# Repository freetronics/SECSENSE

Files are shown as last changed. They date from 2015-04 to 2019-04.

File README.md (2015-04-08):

Security Sensor Shield for Arduino
==================================
Copyright 2013 Freetronics Pty Ltd  
Freetronics site:  www.freetronics.com  
Freetronics email: info@freetronics.com  

Based on the circuit described in the "Security / Automation Sensors"
project in the book "Practical Arduino", this shield allows up to 4
security sensors to be connected with full End-Of-Line (EOL) support to
detect tampering.

Supported sensors include:

 * PIR (passive infrared) motion detectors.
 * Microwave motion detectors.
 * Reed switches.
 * Glass break detectors.
 * Gas detectors.

End-Of-Line technology allows the system to detect a variety of events
using a single cable pair to the sensor, including:

 * Sensor triggered.
 * Sensor cable cut.
 * Sensor cable short-circuited.
 * Sensor housing opened (even when system is disarmed)

Compatible with the Freetronics Eleven, Arduino Uno, and other
compatible boards based on the same header format.

Features:

 * Supports 4 sensor channels simultaneously.
 * Sensor power supply connections totally isolated from the Arduino.
 * Status LED for each sensor channel.
 * Reset button wired through to Arduino reset pin.
 * Green "Sensor power on" LED.
 * Blue "Arduino power on" LED.
 * Overlay guide where you need it: both top and bottom.

More information is available at:

  http://www.freetronics.com/secsense  
  http://www.practicalarduino.com/projects/security-sensors

INSTALLATION
------------
The design is saved as an EAGLE project. EAGLE PCB design software is
available from www.cadsoftusa.com free for non-commercial use. To use
this project download it and place the directory containing these files
into the "eagle" directory on your computer. Then open EAGLE and
navigate to Projects -> eagle -> SECSENSE.

DISTRIBUTION
------------
The specific terms of distribution of this project are governed by the
license referenced below.

LICENSE
-------
Licensed under the TAPR Open Hardware License (www.tapr.org/OHL).
The "license" folder within this repository also contains a copy of
this license in plain text format.

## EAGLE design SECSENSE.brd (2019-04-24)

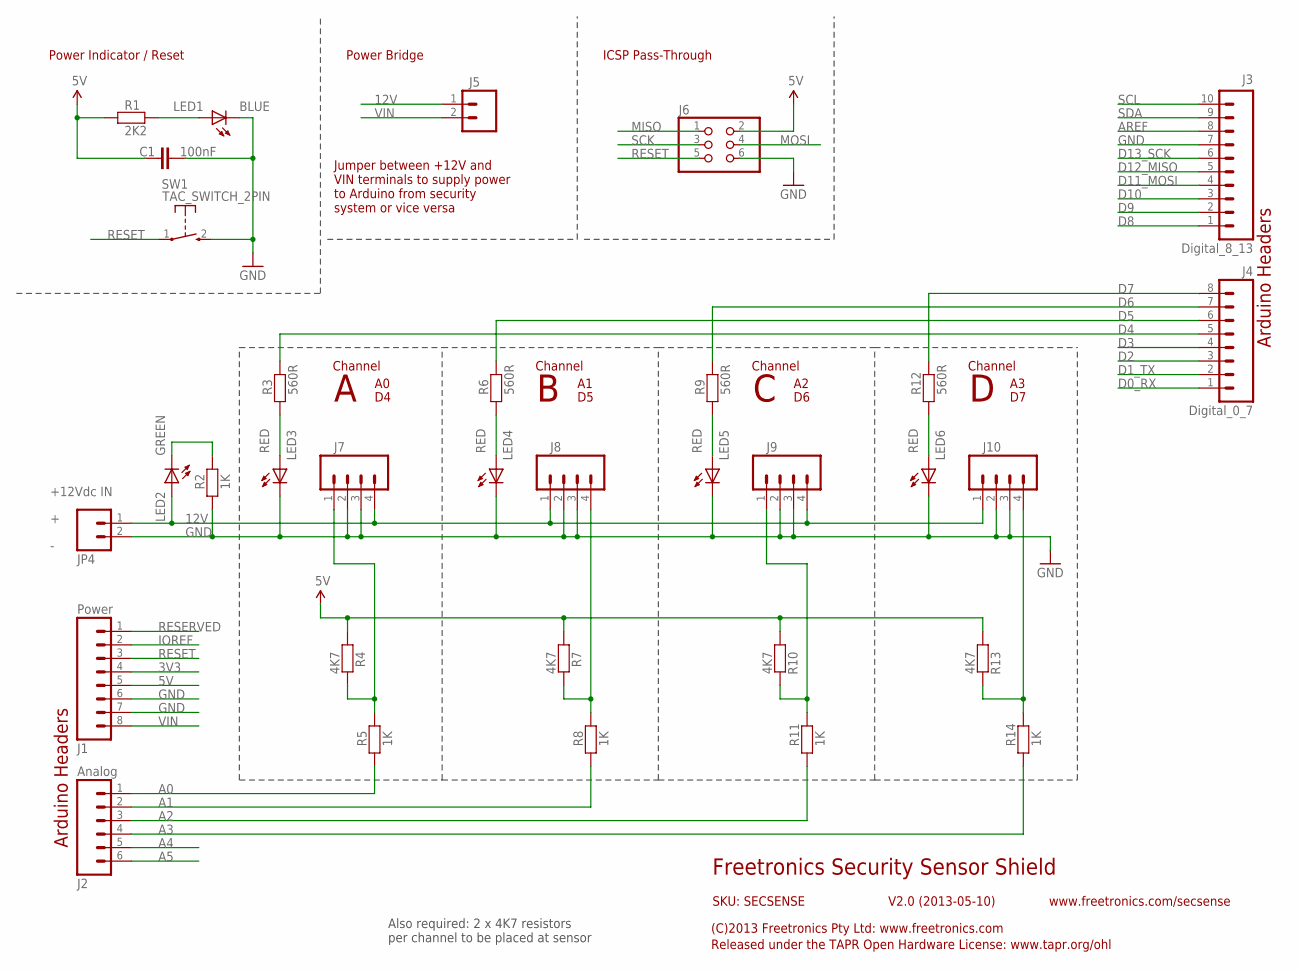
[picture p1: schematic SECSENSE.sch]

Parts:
C1: 100nF; 0603
J1: Power; 1X08
J2: Analog; 1X06
J3: Digital_8_13; 1X10
J4: Digital_0_7; 1X08
J5: M02PTH; 1X02
J6: PINHD-2X3; 2X03
J7, J8, J9, J10: M04SCREW; SCREWTERMINAL-3.5MM-4
JP4: M023.5MM; SCREWTERMINAL-3.5MM-2
LED1: BLUE; LED-0603
LED2: GREEN; LED-0603
LED3, LED4, LED5, LED6: RED; LED-0603
R1: 2K2; 0603
R2, R5, R8, R11, R14: 1K; 0603
R3, R6, R9, R12: 560R; 0603
R4, R7, R10, R13: 4K7; 0603
SW1: TAC_SWITCH_2PIN; TACTILE_SWITCH_SMD_2PIN_TINY

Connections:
3V3: J1.4
5V: C1.1, J1.5, J6.2, R1.1, R4.1, R7.1, R10.1, R13.1
12V: J5.1, J7.4, J8.1, J9.4, J10.1, JP4.1, LED2.A
A0: J2.1, R5.1
A1: J2.2, R8.1
A2: J2.3, R11.1
A3: J2.4, R14.1
A4: J2.5
A5: J2.6
AREF: J3.8
D0_RX: J4.1
D1_TX: J4.2
D2: J4.3
D3: J4.4
D4: J4.5, R3.2
D5: J4.6, R6.2
D6: J4.7, R9.2
D7: J4.8, R12.2
D8: J3.1
D9: J3.2
D10: J3.3
D11_MOSI: J3.4
D12_MISO: J3.5
D13_SCK: J3.6
GND: C1.2, J1.6, J1.7, J3.7, J6.6, J7.2, J7.3, J8.2, J8.3, J9.2, J9.3, J10.2, J10.3, JP4.2, LED1.C, LED3.C, LED4.C, LED5.C, LED6.C, R2.1, SW1.2 (S)
IOREF: J1.2
MISO: J6.1
MOSI: J6.4
unnamed: LED2.C, R2.2
unnamed: LED1.A, R1.2
unnamed: J8.4, R7.2, R8.2
unnamed: J9.1, R10.2, R11.2
unnamed: LED6.A, R12.1
unnamed: LED5.A, R9.1
unnamed: LED4.A, R6.1
unnamed: LED3.A, R3.1
unnamed: J10.4, R13.2, R14.2
unnamed: J7.1, R4.2, R5.2
RESERVED: J1.1
RESET: J1.3, J6.5, SW1.1
SCK: J6.3
SCL: J3.10
SDA: J3.9
VIN: J1.8, J5.2

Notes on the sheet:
Power Indicator / Reset
Arduino Headers
Channel
Power Bridge
Jumper between +12V and VIN terminals to supply power to Arduino from security system or vice versa
+12Vdc IN
Freetronics Security Sensor Shield
V2.0 (2013-05-10)
SKU: SECSENSE
(C)2013 Freetronics Pty Ltd: www.freetronics.com
Released under the TAPR Open Hardware License: www.tapr.org/ohl
www.freetronics.com/secsense
ICSP Pass-Through
Also required: 2 x 4K7 resistors per channel to be placed at sensor

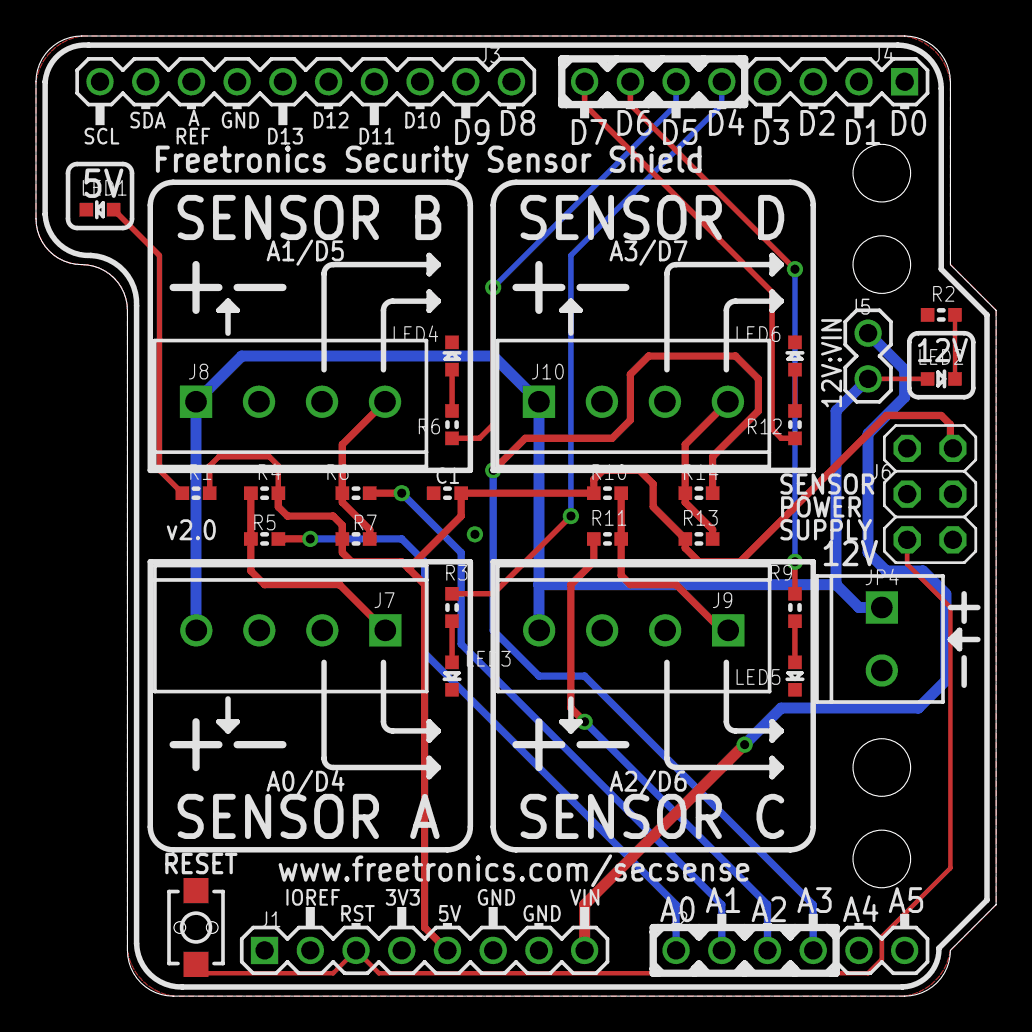
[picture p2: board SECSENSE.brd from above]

Board: 2 copper layers, 53.3 x 53.3 mm, 33 parts (0 on the bottom side), 23 nets.

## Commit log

2015-04-08 Initial import using new layout, ready for v2.0 release
    [SECSENSE.brd, SECSENSE.sch]
2019-04-24 Improve designators
    [SECSENSE.brd]

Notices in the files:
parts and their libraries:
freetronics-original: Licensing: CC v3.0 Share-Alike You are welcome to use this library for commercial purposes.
